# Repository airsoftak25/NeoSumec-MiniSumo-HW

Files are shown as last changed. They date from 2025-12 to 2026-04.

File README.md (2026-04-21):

# NeoSumec-MiniSumo-HW

# Description 
In this reposirotry contains: PCB, Gerber, cut files and other stuff about elektronics for our Minisumo robots

|Folder name|what is it|
|:-:|:-|
|MK-1|Contains HW design for our first MiniSumo robot **MK-1**|
|MK3|Folder with our desighn of pcb for MK3, *dont used* (From team [**Sumec**](https://github.com/bismarx-v1/Sumec-MiniSumo-HW/tree/46f5fd0a021a236c40a02696af7fbdfdfe6c01d2))|

# Contributors
People witch work on some part of HW for our MiniSumo Robots
| Name | Part |
|:-:|:-|
| Vadim Sobčuk | Head of PCB and cut Design |

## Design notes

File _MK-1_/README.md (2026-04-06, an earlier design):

# MK-1 

# Description 
This folder contains all files of PCB design for our first MiniSumo robot **MK-1** from team **NeoSumec**

# Features for PCB 
This list is orientational. Some of the features maybe will not apeare on a pcb.

* **2 or 3 mounting holes**
* **LED on io**
  * **RGB LED prog**
* **Buttons on io**
  * **boot and en Buttons**
* *Buzzer*
* **Connectors for senzors and motors**
  * *Con for fan via jumper*
* **Undervoltage protection**
* **StepDown 3V3** *(Maybe 5V)*
* **ESP32-S3**

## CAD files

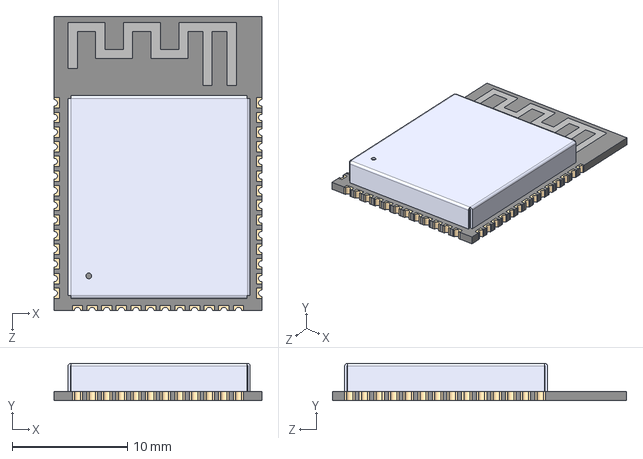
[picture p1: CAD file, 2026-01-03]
.LibFiles/neo_sumec_3d/ESP32-S3-WROOM-1-N8.step
18.0 x 3.25 x 25.5 mm

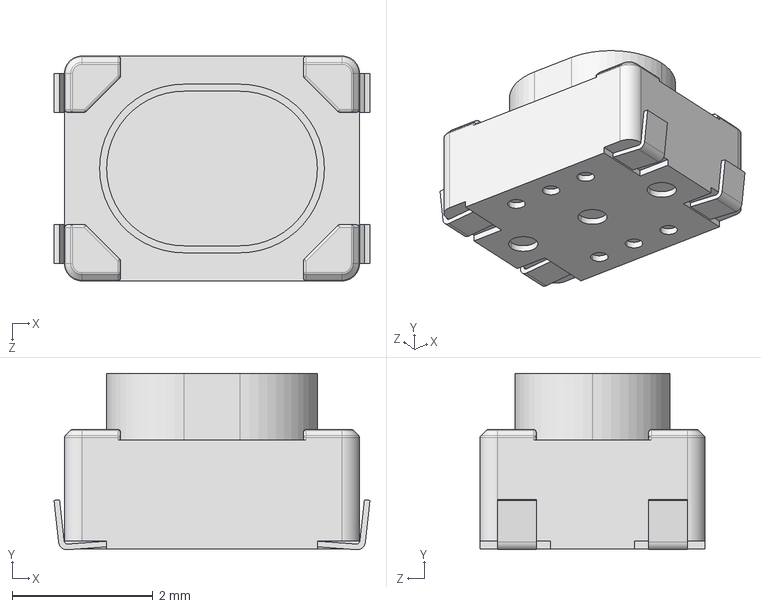
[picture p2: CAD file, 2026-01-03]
.LibFiles/neo_sumec_3d/TL3365AF180QG.step
4.50 x 2.51 x 3.20 mm

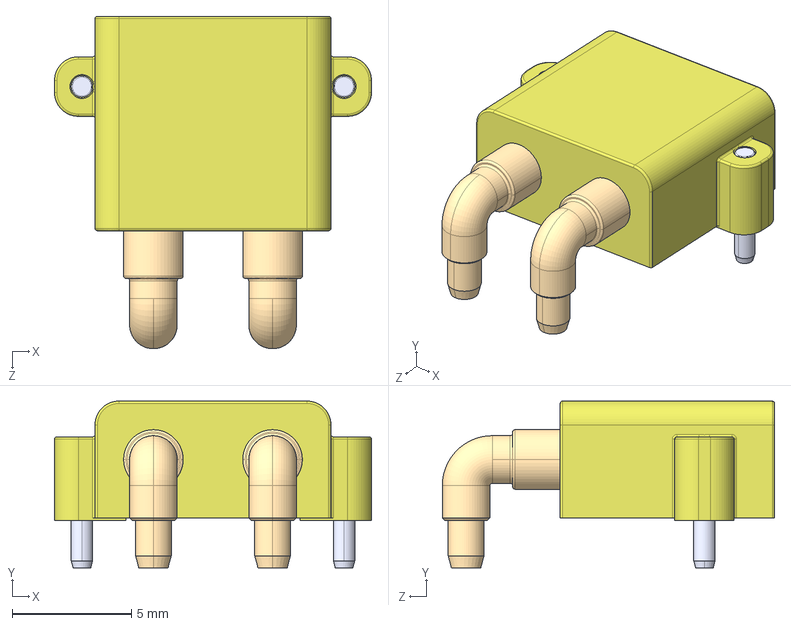
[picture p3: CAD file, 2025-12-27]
.LibFiles/neo_sumec_3d/XT30PW-M.step
13.3 x 7.00 x 14.0 mm

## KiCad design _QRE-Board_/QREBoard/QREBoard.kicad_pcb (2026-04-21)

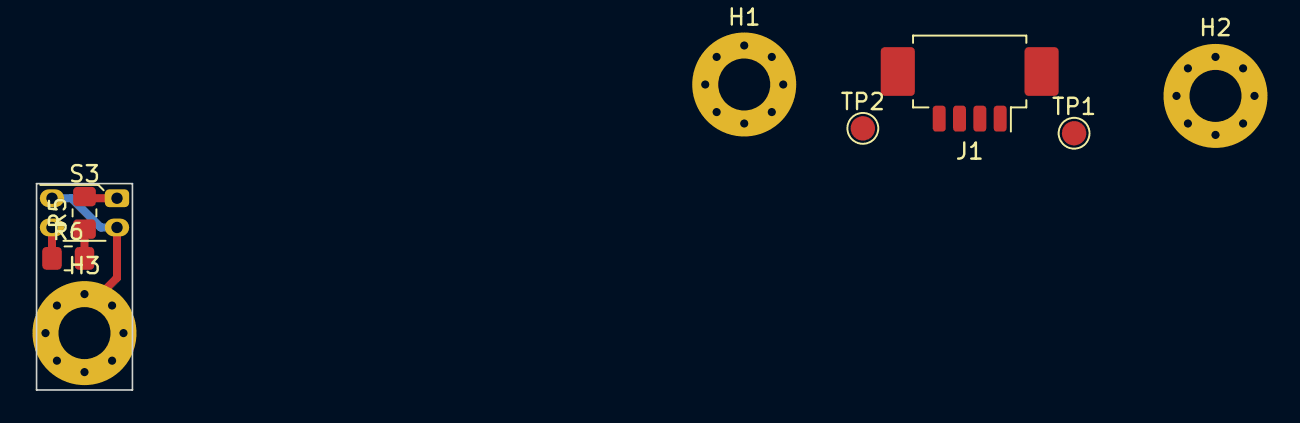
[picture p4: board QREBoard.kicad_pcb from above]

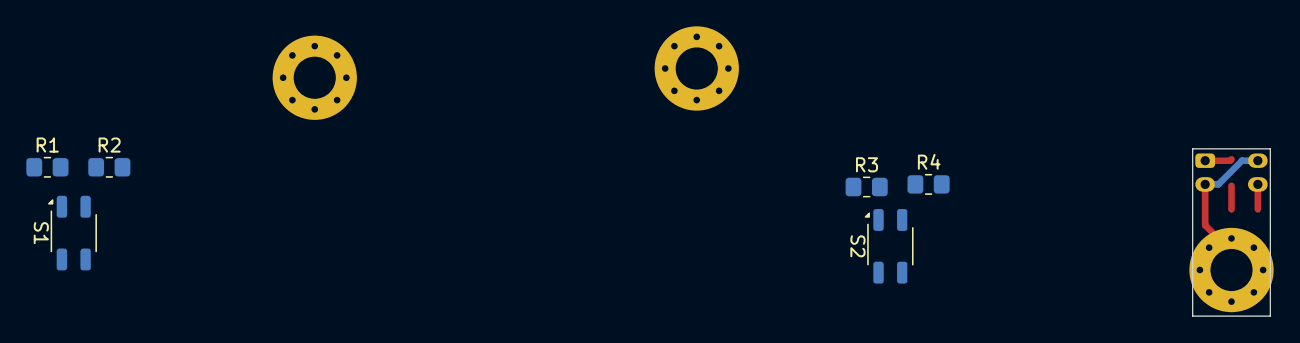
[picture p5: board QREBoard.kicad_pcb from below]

Board: 2 copper layers, 15 parts (6 on the bottom side), 8 nets.

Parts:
H1, H2, H3: M3; MountingHole_3.2mm_M3_Pad_Via
J1: Conn_01x04_Pin; Molex_PicoBlade_53261-0471_1x04-1MP_P1.25mm_Horizontal
R1, R3, R5: 100R; R_0805_2012Metric_Pad1.20x1.40mm_HandSolder
R2, R4, R6: 10K; R_0805_2012Metric_Pad1.20x1.40mm_HandSolder
S1, S2: QRE1113GR; OnSemi_CASE100CY
S3: QRE1113; OnSemi_CASE100AQ
TP1: QRE_Left; TestPoint_Pad_D1.5mm
TP2: QRE_Right; TestPoint_Pad_D1.5mm

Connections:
+3V3: J1.2, R1.1, R2.2, R3.1, R4.2, R5.1, R6.2
GND: H1.1 (1_1), H2.1 (1_1), H3.1 (1_1), J1.3, S1.2 (K), S1.4, S2.2 (K), S2.4, S3.2 (K), S3.4
unnamed: R1.2, S1.1 (A)
unnamed: R3.2, S2.1 (A)
unnamed: R5.2, S3.1 (A)
QRE_Back: R6.1, S3.3
QRE_Left: J1.1, R2.1, S1.3, TP1.1 (1_1)
QRE_Right: J1.4, R4.1, S2.3, TP2.1 (1_1)

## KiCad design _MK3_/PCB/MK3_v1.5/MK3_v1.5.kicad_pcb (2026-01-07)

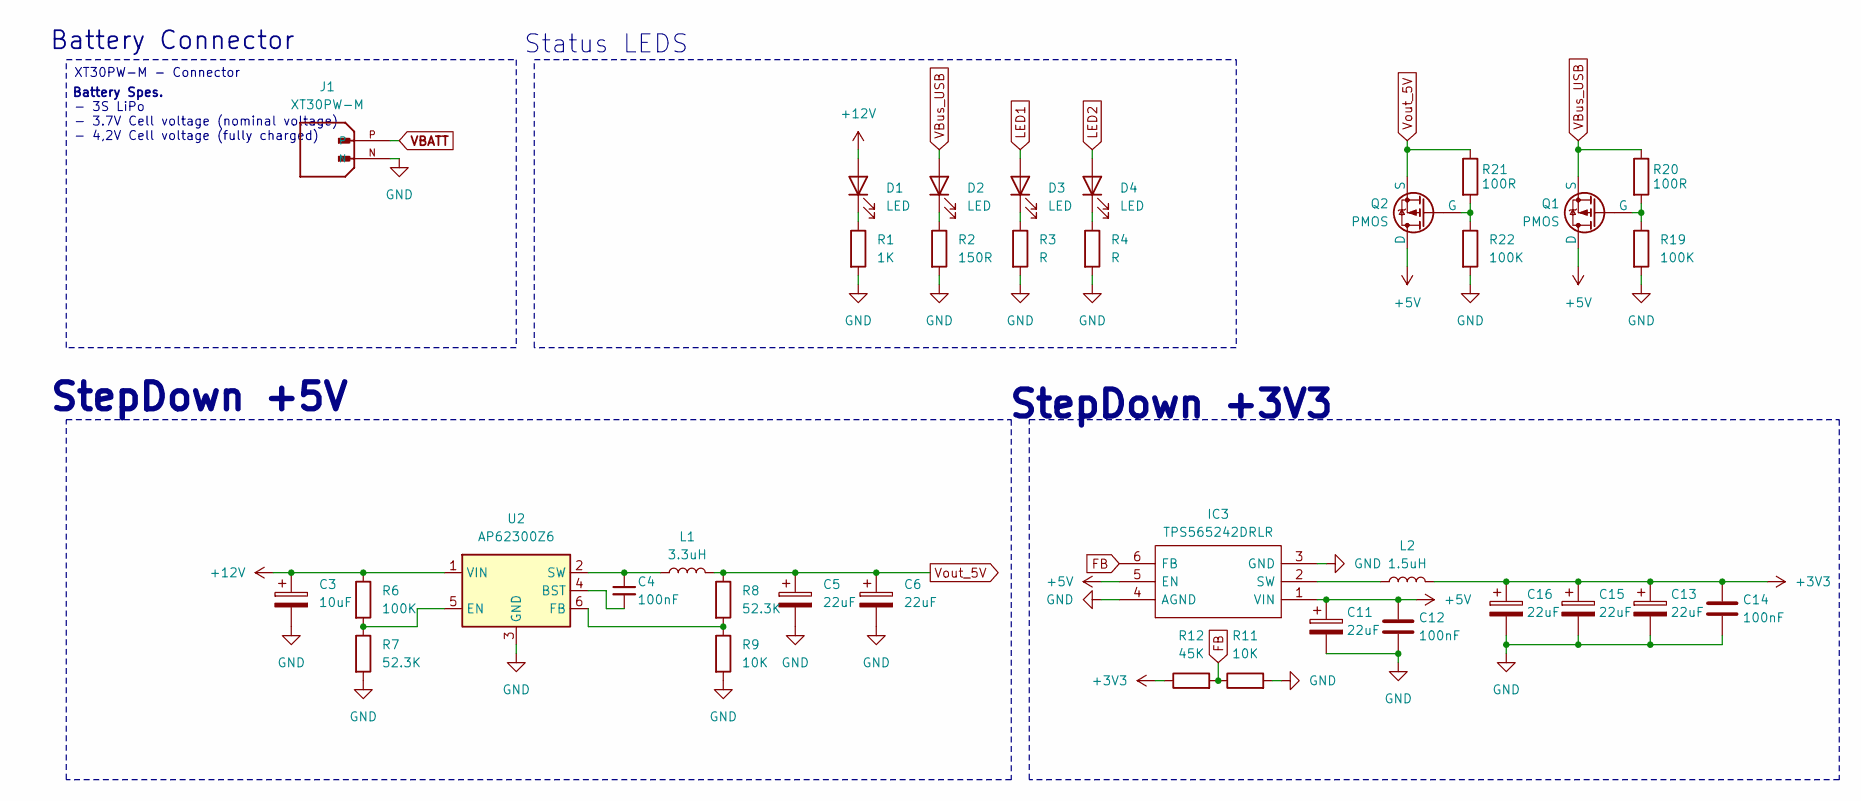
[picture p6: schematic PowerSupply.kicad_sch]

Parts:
C3: 10uF; CP_EIA-3216-18_Kemet-A_HandSolder
C4, C12, C14: 100nF; C_0805_2012Metric_Pad1.18x1.45mm_HandSolder
C5, C6, C11, C13, C15, C16: 22uF; CP_EIA-3216-18_Kemet-A_HandSolder
D1, D2, D3, D4: LED; LED_0805_2012Metric_Pad1.15x1.40mm_HandSolder
IC3: TPS565242DRLR; SOT-563; Manufacturer_Part_Number TPS565242DRLR; Mouser Part Number 595-TPS565242DRLR
J1: XT30PW-M; AMASS_XT30PW-M; PARTREV 1.2
L1: 3.3uH; L_Vishay_IHLP-1616
L2: 1.5uH; L_Vishay_IHLP-1212
Q1, Q2: PMOS; SOT-23
R1: 1K; R_0805_2012Metric_Pad1.20x1.40mm_HandSolder
R2: 150R; R_0805_2012Metric_Pad1.20x1.40mm_HandSolder
R3, R4: R; R_0805_2012Metric_Pad1.20x1.40mm_HandSolder
R6, R19, R22: 100K; R_0805_2012Metric_Pad1.20x1.40mm_HandSolder
R7, R8: 52.3K; R_0805_2012Metric_Pad1.20x1.40mm_HandSolder
R9, R11: 10K; R_0805_2012Metric_Pad1.20x1.40mm_HandSolder
R12: 45K; R_0805_2012Metric_Pad1.20x1.40mm_HandSolder
R20, R21: 100R; R_0805_2012Metric_Pad1.20x1.40mm_HandSolder
U2: AP62300Z6; SOT-563

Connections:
+3V3: C13.1, C14.1, C15.1, C16.1, L2.2, R12.1; also elsewhere on the board
+5V: C11.1, C12.1, IC3.1 (VIN), IC3.5 (EN), Q1.1 (D), Q2.1 (D); also elsewhere on the board
+12V: C3.1, D1.2 (A), R6.1, U2.1 (VIN); also elsewhere on the board
FB: IC3.6 (FB), R11.1, R12.2
GND: C3.2, C5.2, C6.2, C11.2, C12.2, C13.2, C14.2, C15.2, C16.2, IC3.3 (GND), IC3.4 (AGND), J1.N, R1.2, R2.2, R3.2, R4.2, R7.2, R9.2, R11.2, R19.2, R22.2, U2.3 (GND); also elsewhere on the board
LED1: D3.2 (A); also elsewhere on the board
LED2: D4.2 (A); also elsewhere on the board
unnamed: D1.1 (K), R1.1
unnamed: D2.1 (K), R2.1
unnamed: D3.1 (K), R3.1
unnamed: D4.1 (K), R4.1
unnamed: IC3.2 (SW), L2.1
unnamed: Q1.2 (G), R19.1, R20.2
unnamed: Q2.2 (G), R21.2, R22.1
unnamed: C4.2, U2.4 (BST)
unnamed: R6.2, R7.1, U2.5 (EN)
unnamed: R8.2, R9.1, U2.6 (FB)
unnamed: C4.1, L1.1, U2.2 (SW)
VBATT: J1.P; also elsewhere on the board
VBus_USB: D2.2 (A), Q1.3 (S), R20.1; also elsewhere on the board
Vout_5V: C5.1, C6.1, L1.2, Q2.3 (S), R8.1, R21.1

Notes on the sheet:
Battery Spes.
StepDown +5V
Battery Connector
Status LEDS
XT30PW-M - Connector
- 3S LiPo - 3.7V Cell voltage (nominal voltage) - 4,2V Cell voltage (fully charged)
StepDown +3V3

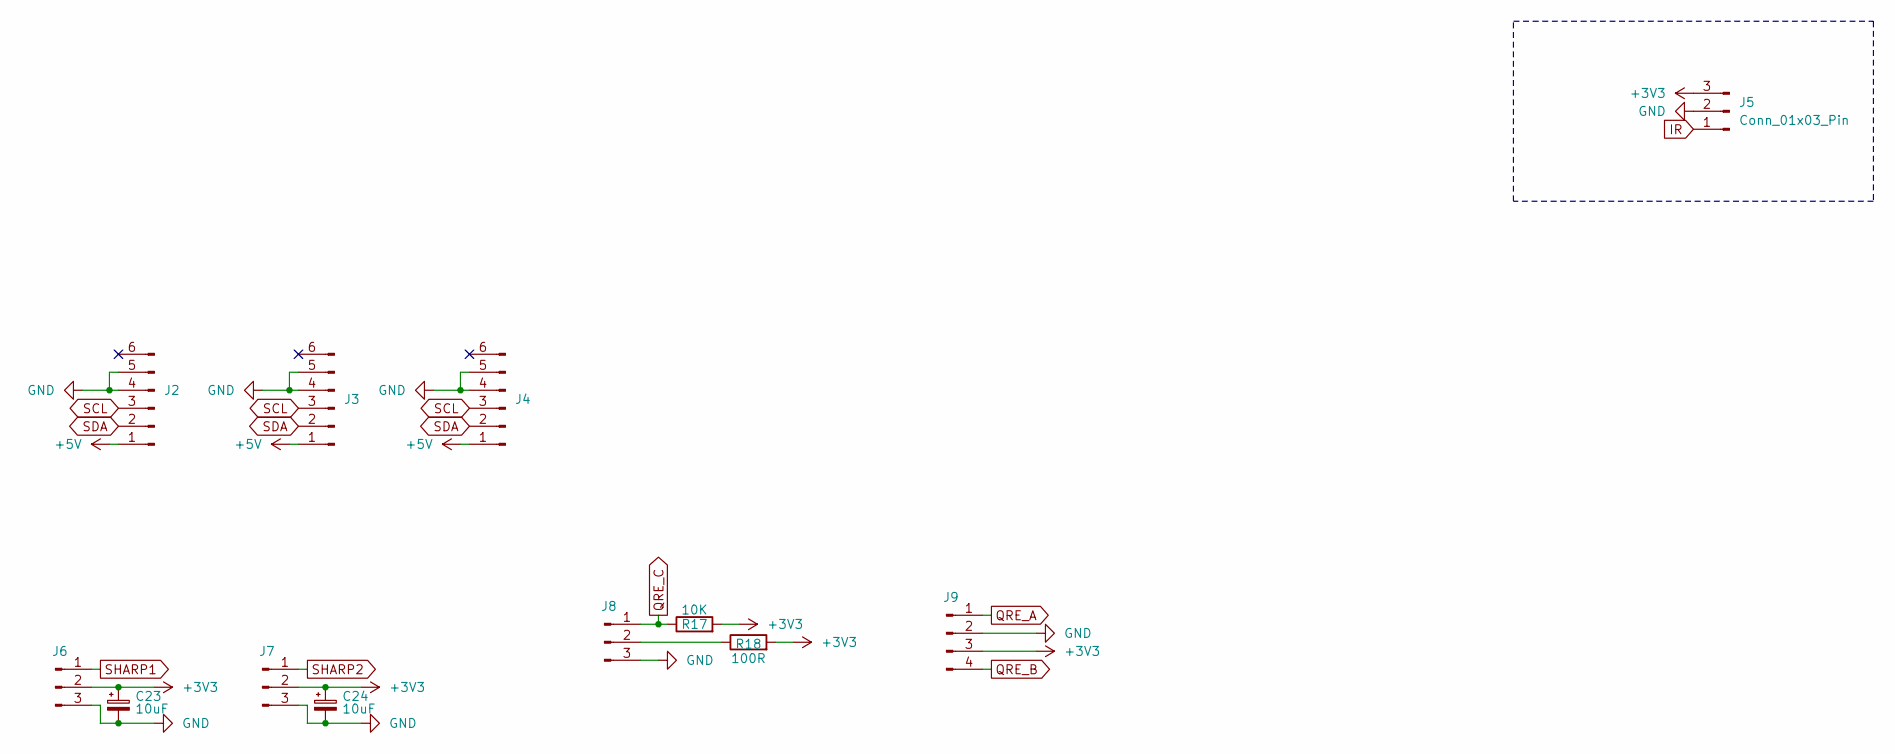
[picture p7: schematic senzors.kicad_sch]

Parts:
C23, C24: 10uF; CP_EIA-3216-18_Kemet-A_HandSolder
J2, J3, J4: Conn_01x06_Pin; Molex_PicoBlade_53398-0671_1x06-1MP_P1.25mm_Vertical
J5: Conn_01x03_Pin; PinSocket_1x03_P2.54mm_Vertical
J6, J7, J8: Conn_01x03_Pin; Molex_PicoBlade_53398-0371_1x03-1MP_P1.25mm_Vertical
J9: Conn_01x04_Pin; Molex_PicoBlade_53398-0471_1x04-1MP_P1.25mm_Vertical
R17: 10K; R_0805_2012Metric_Pad1.20x1.40mm_HandSolder
R18: 100R; R_0805_2012Metric_Pad1.20x1.40mm_HandSolder

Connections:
+3V3: C23.1, C24.1, J5.3, J6.2, J7.2, J9.3, R17.2, R18.2; also elsewhere on the board
+5V: J2.1, J3.1, J4.1; also elsewhere on the board
GND: C23.2, C24.2, J2.4, J2.5, J3.4, J3.5, J4.4, J4.5, J5.2, J6.3, J7.3, J8.3, J9.2; also elsewhere on the board
IR: J5.1; also elsewhere on the board
unnamed: J8.2, R18.1
QRE_A: J9.1; also elsewhere on the board
QRE_B: J9.4; also elsewhere on the board
QRE_C: J8.1, R17.1; also elsewhere on the board
SCL: J2.3, J3.3, J4.3; also elsewhere on the board
SDA: J2.2, J3.2, J4.2; also elsewhere on the board
SHARP1: J6.1; also elsewhere on the board
SHARP2: J7.1; also elsewhere on the board

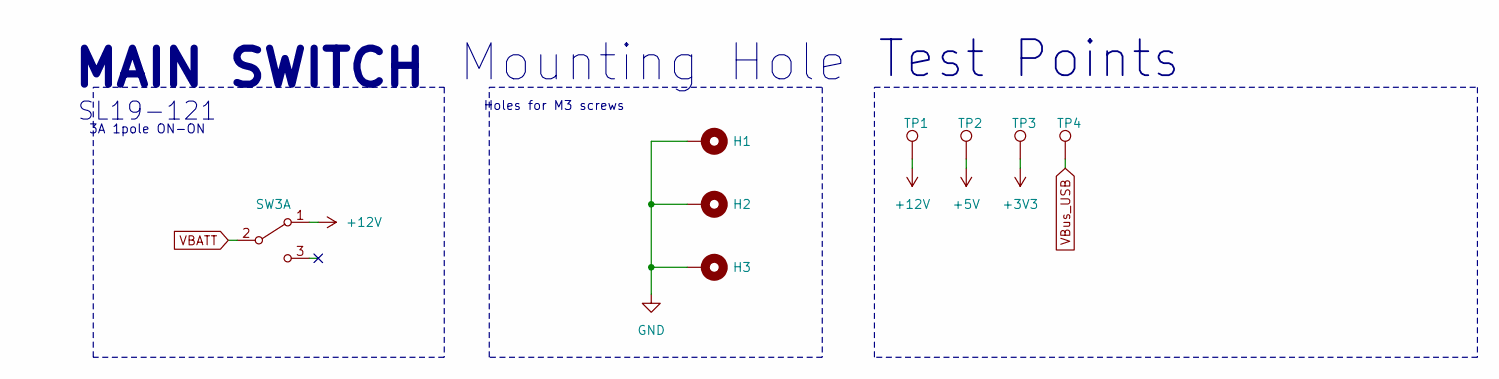
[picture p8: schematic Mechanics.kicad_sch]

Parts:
H1, H2, H3: MountingHole_Pad; MountingHole_3.2mm_M3_Pad
SW3: SW_DPDT_x2; 255SB
TP1, TP2, TP3, TP4: TestPoint; TestPoint_Pad_D1.0mm

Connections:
+3V3: TP3.1; also elsewhere on the board
+5V: TP2.1; also elsewhere on the board
+12V: SW3.1 (A), TP1.1; also elsewhere on the board
GND: H1.1, H2.1, H3.1; also elsewhere on the board
VBATT: SW3.2 (B); also elsewhere on the board
VBus_USB: TP4.1; also elsewhere on the board

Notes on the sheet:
3A 1pole ON-ON
Mounting Hole
SL19-121
Holes for M3 screws
Test Points
MAIN SWITCH

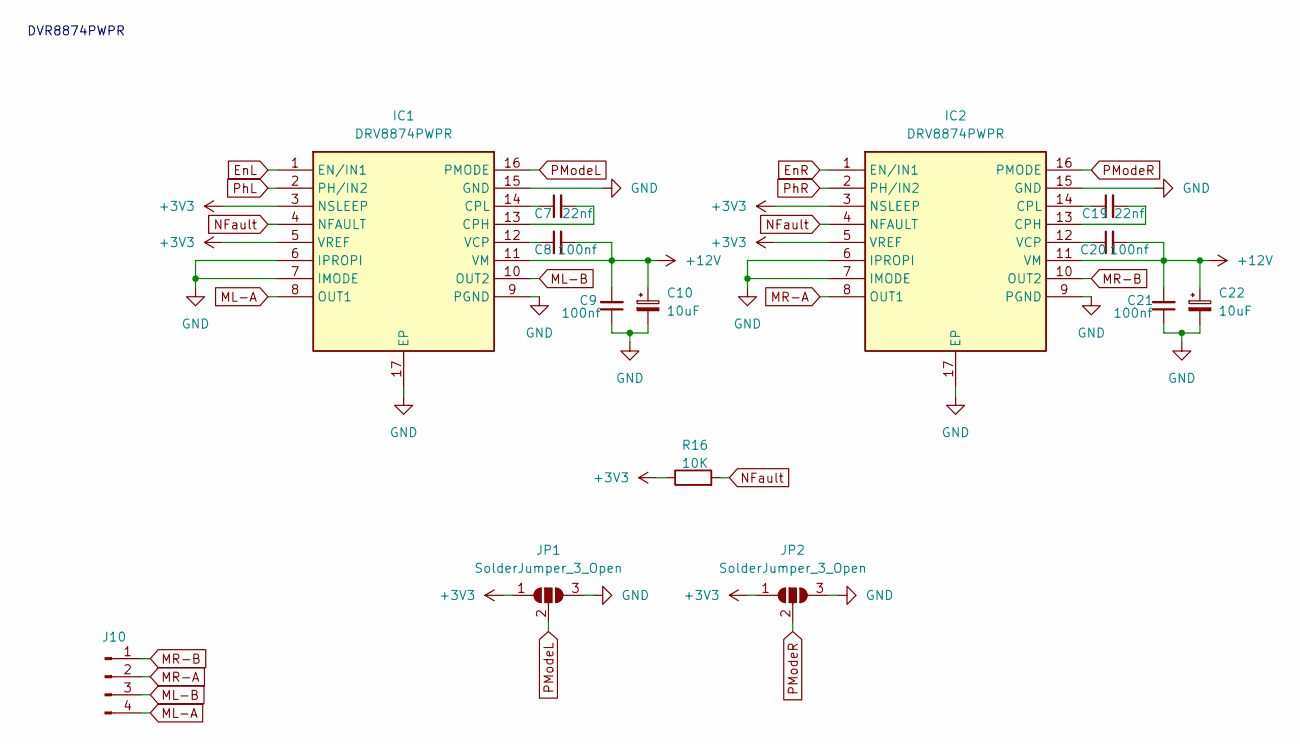
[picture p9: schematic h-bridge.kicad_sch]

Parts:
C7, C19: 22nf; C_0805_2012Metric_Pad1.18x1.45mm_HandSolder
C8, C9, C20, C21: 100nf; C_0805_2012Metric_Pad1.18x1.45mm_HandSolder
C10, C22: 10uF; CP_EIA-3216-18_Kemet-A_HandSolder
IC1, IC2: DRV8874PWPR; DRV8874; Manufacturer_Part_Number DRV8874PWPR; Mouser Part Number 595-DRV8874PWPR
J10: Conn_01x04_Pin; JST_XH_B4B-XH-A_1x04_P2.50mm_Vertical
JP1, JP2: SolderJumper_3_Open; SolderJumper-3_P2.0mm_Open_TrianglePad1.0x1.5mm
R16: 10K; R_0805_2012Metric_Pad1.20x1.40mm_HandSolder

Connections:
+3V3: IC1.3 (NSLEEP), IC1.5 (VREF), IC2.3 (NSLEEP), IC2.5 (VREF), JP1.1 (A), JP2.1 (A), R16.1; also elsewhere on the board
+12V: C8.2, C9.2, C10.1, C20.2, C21.2, C22.1, IC1.11 (VM), IC2.11 (VM); also elsewhere on the board
EnL: IC1.1 (EN/IN1); also elsewhere on the board
EnR: IC2.1 (EN/IN1); also elsewhere on the board
GND: C9.1, C10.2, C21.1, C22.2, IC1.6 (IPROPI), IC1.7 (IMODE), IC1.9 (PGND), IC1.15 (GND), IC1.17 (EP), IC2.6 (IPROPI), IC2.7 (IMODE), IC2.9 (PGND), IC2.15 (GND), IC2.17 (EP), JP1.3 (B), JP2.3 (B); also elsewhere on the board
ML-A: IC1.8 (OUT1), J10.4
ML-B: IC1.10 (OUT2), J10.3
MR-A: IC2.8 (OUT1), J10.2
MR-B: IC2.10 (OUT2), J10.1
NFault: IC1.4 (NFAULT), IC2.4 (NFAULT), R16.2; also elsewhere on the board
unnamed: C7.2, IC1.13 (CPH)
unnamed: C7.1, IC1.14 (CPL)
unnamed: C8.1, IC1.12 (VCP)
unnamed: C19.2, IC2.13 (CPH)
unnamed: C19.1, IC2.14 (CPL)
unnamed: C20.1, IC2.12 (VCP)
PModeL: IC1.16 (PMODE), JP1.2 (C)
PModeR: IC2.16 (PMODE), JP2.2 (C)
PhL: IC1.2 (PH/IN2); also elsewhere on the board
PhR: IC2.2 (PH/IN2); also elsewhere on the board

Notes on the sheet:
DVR8874PWPR

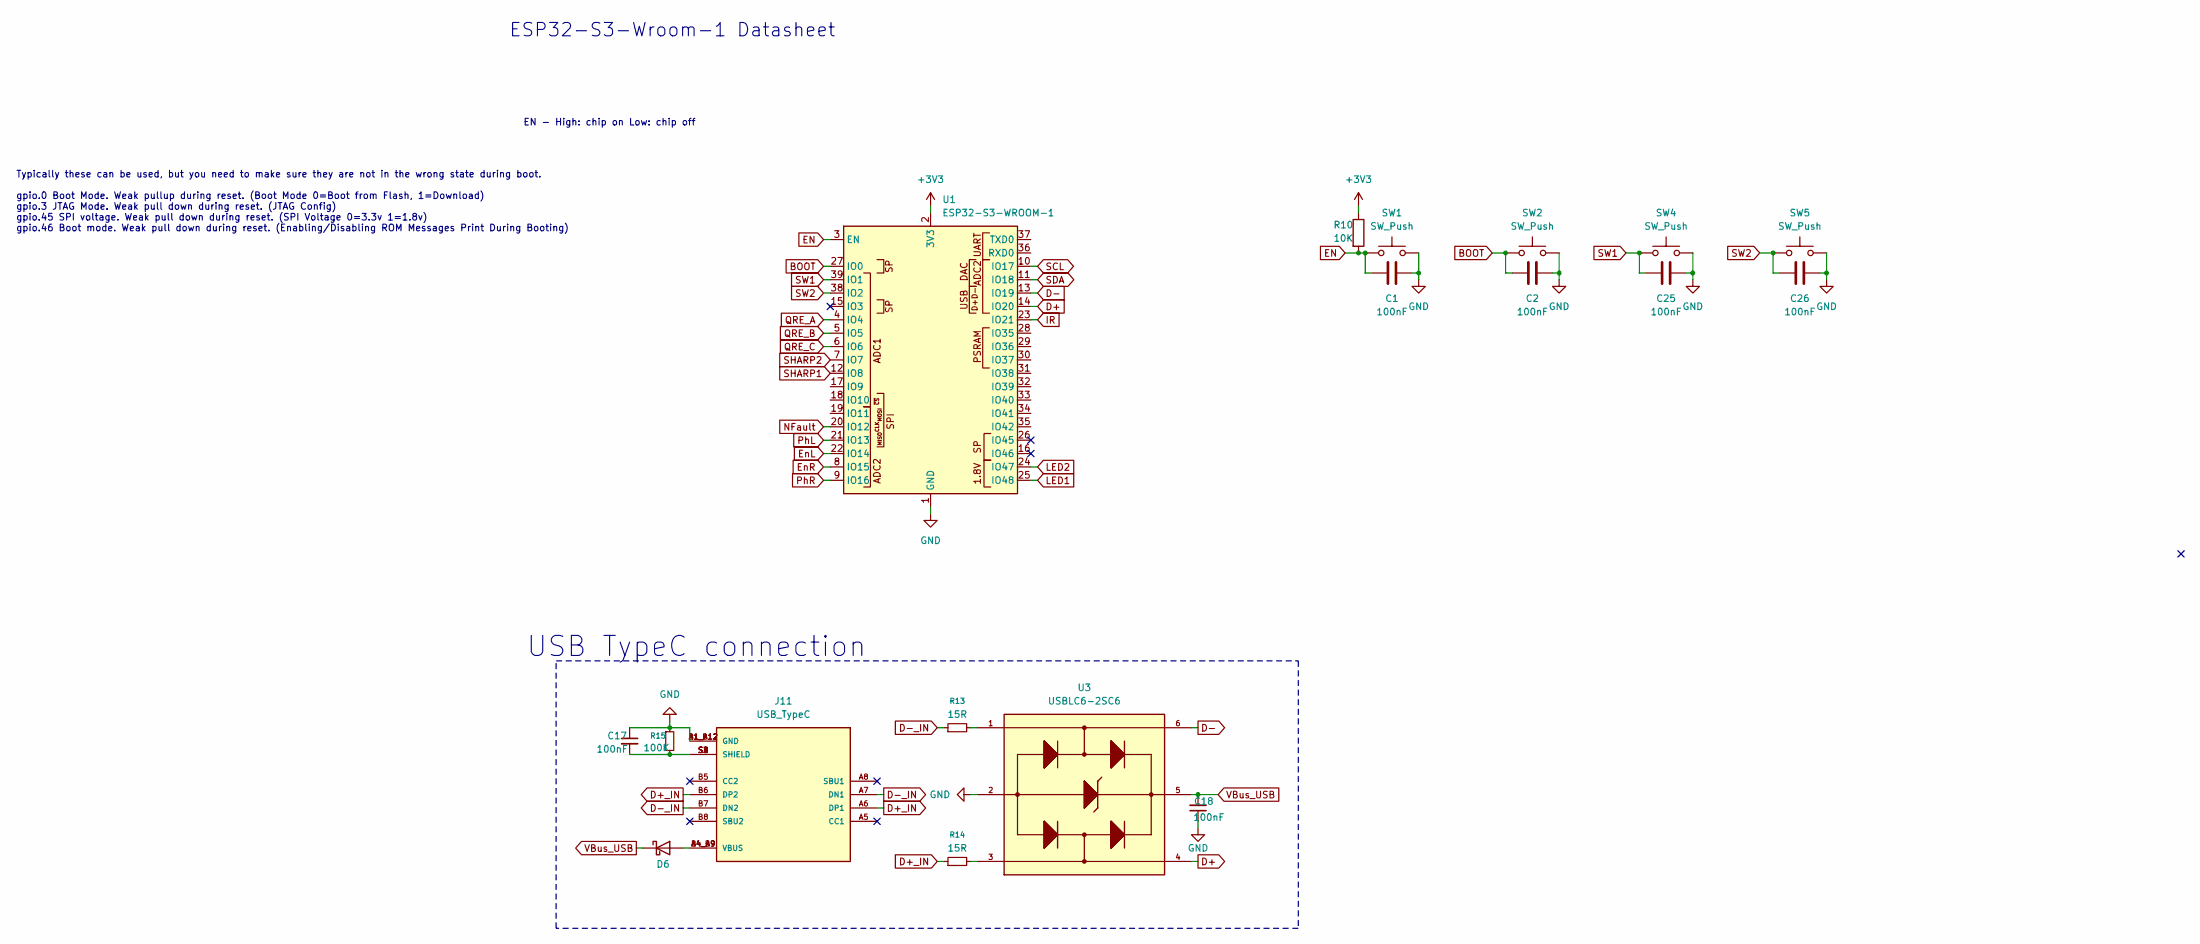
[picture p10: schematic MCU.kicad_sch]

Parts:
C1, C2, C17, C18, C25, C26: 100nF; C_0805_2012Metric_Pad1.18x1.45mm_HandSolder
D6: D_Schottky; D_1206_3216Metric_Pad1.42x1.75mm_HandSolder
J11: USB_TypeC; HRO_TYPE-C-31-M-12; PARTREV 2020.12.08
R10: 10K; R_0805_2012Metric_Pad1.20x1.40mm_HandSolder
R13, R14: 15R; R_0805_2012Metric_Pad1.20x1.40mm_HandSolder
R15: 100K; R_0805_2012Metric_Pad1.20x1.40mm_HandSolder
SW1, SW2, SW4, SW5: SW_Push; SW_TL3365AF180QG
U1: ESP32-S3-WROOM-1; XCVR_ESP32-S3-WROOM-1-N8
U3: USBLC6-2SC6; SOT-23-6

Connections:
+3V3: R10.1, U1.2 (3V3); also elsewhere on the board
BOOT: C2.2, SW2.1, U1.27 (IO0)
D+: U1.14 (IO20), U3.4
D+_IN: J11.A6 (DP1), J11.B6 (DP2), R14.1
D-: U1.13 (IO19), U3.6
D-_IN: J11.A7 (DN1), J11.B7 (DN2), R13.1
EN: C1.2, R10.2, SW1.1, U1.3 (EN)
EnL: U1.22 (IO14); also elsewhere on the board
EnR: U1.8 (IO15); also elsewhere on the board
GND: C1.1, C2.1, C17.1, C18.1, C25.1, C26.1, J11.A1_B12 (GND), J11.B1_A12 (GND), R15.1, SW1.2, SW2.2, SW4.2, SW5.2, U1.1 (GND), U1.40 (GND), U1.41 (GND), U3.2; also elsewhere on the board
IR: U1.23 (IO21); also elsewhere on the board
LED1: U1.25 (IO48); also elsewhere on the board
LED2: U1.24 (IO47); also elsewhere on the board
NFault: U1.20 (IO12); also elsewhere on the board
unnamed: C17.2, J11.S1 (SHIELD), J11.S2 (SHIELD), J11.S3 (SHIELD), J11.S4 (SHIELD), R15.2
unnamed: D6.2 (A), J11.A4_B9 (VBUS), J11.B4_A9 (VBUS)
unnamed: R13.2, U3.1
unnamed: R14.2, U3.3
PhL: U1.21 (IO13); also elsewhere on the board
PhR: U1.9 (IO16); also elsewhere on the board
QRE_A: U1.4 (IO4); also elsewhere on the board
QRE_B: U1.5 (IO5); also elsewhere on the board
QRE_C: U1.6 (IO6); also elsewhere on the board
SCL: U1.10 (IO17); also elsewhere on the board
SDA: U1.11 (IO18); also elsewhere on the board
SHARP1: U1.12 (IO8); also elsewhere on the board
SHARP2: U1.7 (IO7); also elsewhere on the board
SW1: C25.2, SW4.1, U1.39 (IO1)
SW2: C26.2, SW5.1, U1.38 (IO2)
VBus_USB: C18.2, D6.1 (K), U3.5; also elsewhere on the board

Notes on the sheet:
ESP32-S3-Wroom-1 Datasheet
EN - High: chip on Low: chip off
USB TypeC connection
Typically these can be used, but you need to make sure they are not in the wrong state during boot. gpio.0 Boot Mode. Weak pullup during reset. (Boot Mode 0=Boot from Flash, 1=Download) gpio.3 JTAG Mode. Weak pull down during reset. (JTAG Config) gpio.45 SPI voltage. Weak pull down during reset. (S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

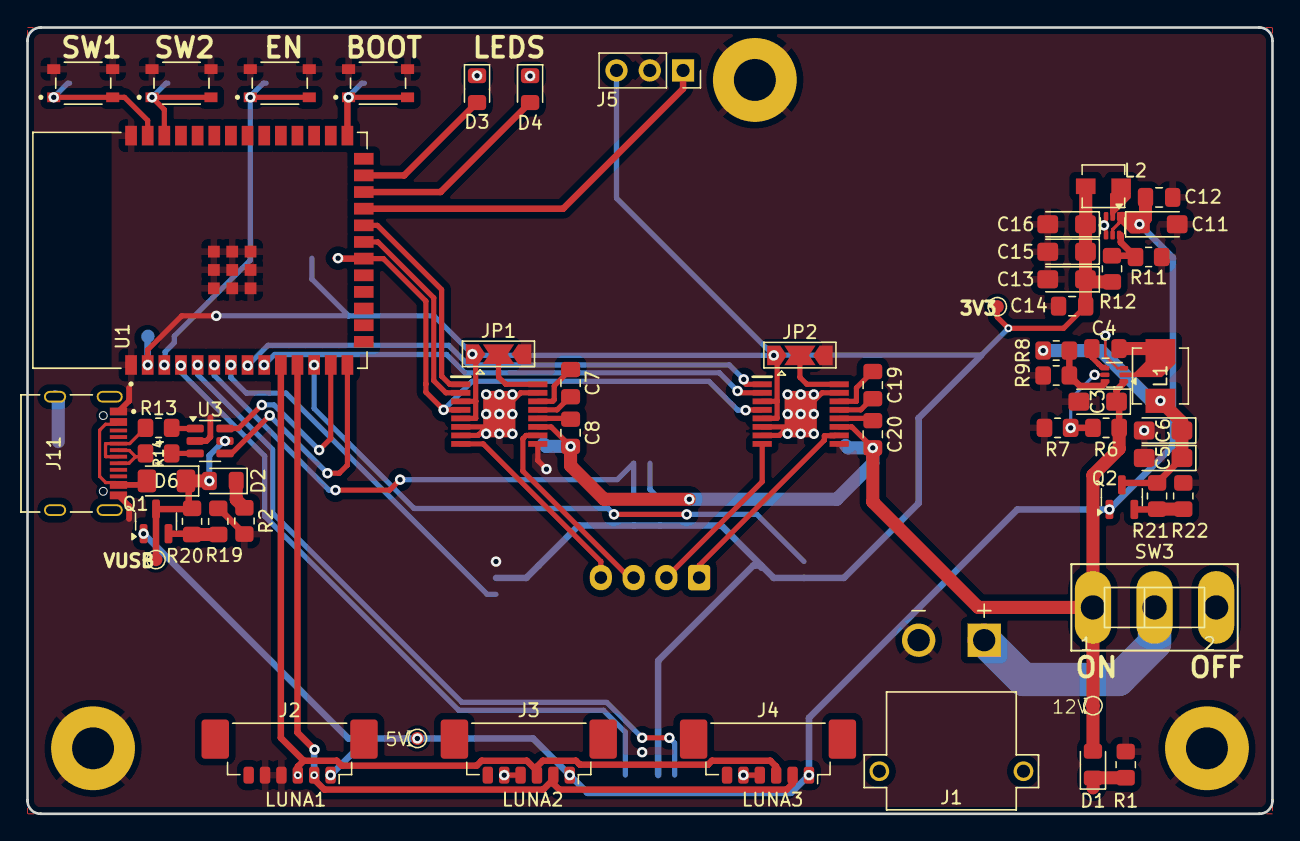
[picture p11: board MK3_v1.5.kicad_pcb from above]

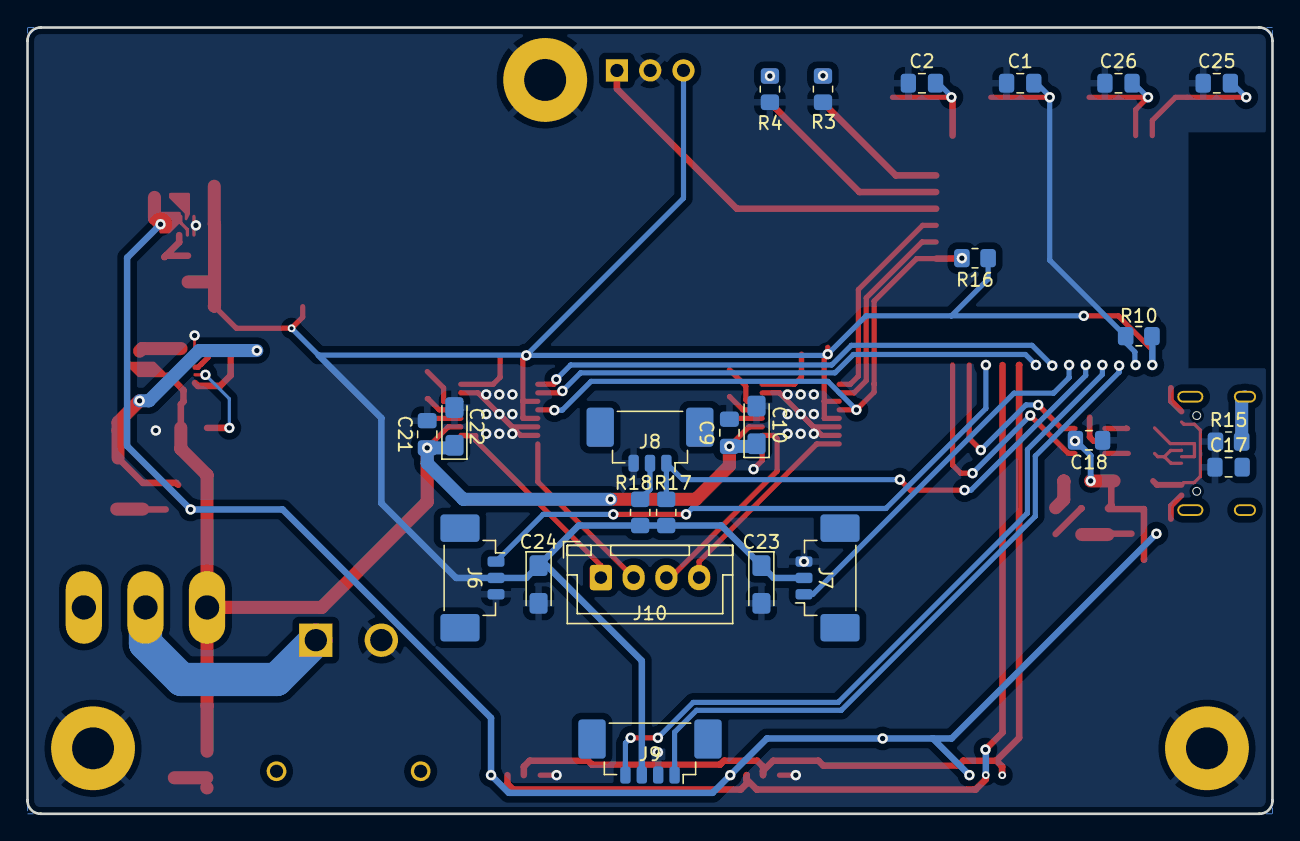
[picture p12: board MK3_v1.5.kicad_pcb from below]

Board: 2 copper layers, 95.0 x 60.0 mm, 87 parts (24 on the bottom side), 59 nets.

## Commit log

2025-12-27 First push
    this contain gitnore, preparation for updates and other stuff
    [Additonal BOM mouser.xls, Additonal BOM.xlsx, COMPOUND.ipt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]
2026-01-03 MK3_v1.5
    work in progress
    [Additonal BOM mouser.xls, Additonal BOM.xlsx, COMPOUND.ipt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]
2026-01-04 PCB UPDATE
    [MK3_v1.5.kicad_pcb, Mechanics.kicad_sch, PowerSupply.kicad_sch]
2026-01-07 pcb done
    [MCU.kicad_sch, MK3_v1.5.kicad_pcb, PowerSupply.kicad_sch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]
2026-03-22 Create MK-1
    [NeoSumec_MK-1.kicad_pcb, NeoSumec_MK-1.kicad_sch]
2026-04-06 Added QRE Board and features list for MK-1
    [QREBoard.kicad_pcb, QREBoard.kicad_sch]
2026-04-21 some changes
    [QREBoard.kicad_pcb, QREBoard.kicad_sch]
